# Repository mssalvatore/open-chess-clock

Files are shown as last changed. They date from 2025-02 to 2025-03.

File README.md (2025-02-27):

# Open Chess Clock

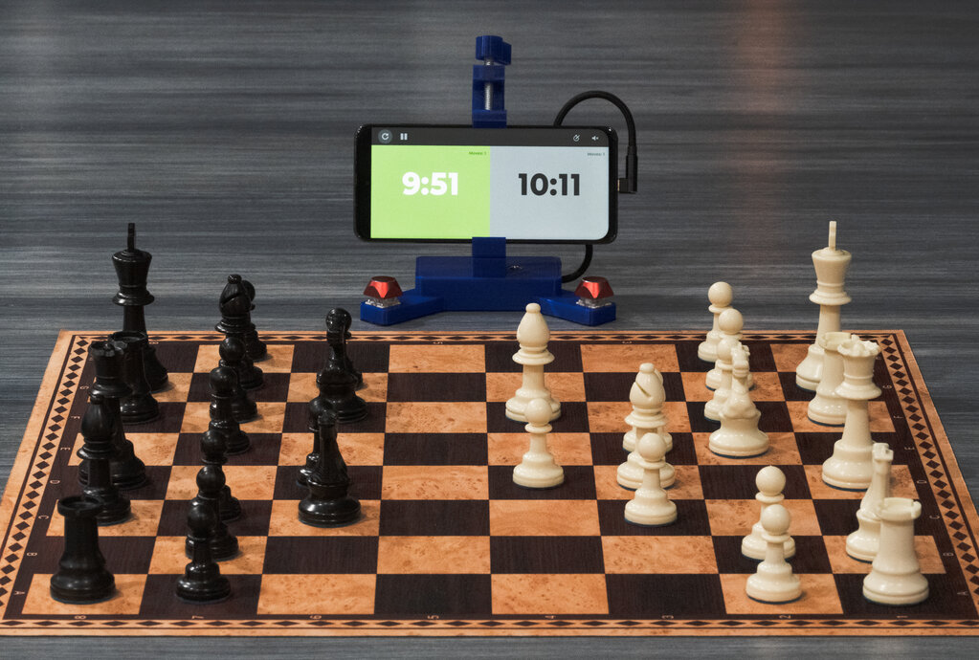
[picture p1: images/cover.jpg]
Open Chess Clock


## Summary
Open Chess Clock is a completely open-source chess/game clock consisting of
both off-the-shelf and 3D-printed parts. The goals of this project are to
create a chess clock that

- is easy and intuitive to set.
- supports multiple time control modes.
- doesn't become a brick if the vendor goes out of business.
- enables the use of clocks with n-player games.
- is inexpensive and accessible.
- is completely customizable.

The first version of this clock is powered by [Chess.com's Android chess clock
app](https://github.com/ChessCom/android-chessclock), which is licensed under
MPL-2.0. This app will likely be replaced in version 2 so that two devices may
be paired in order to play 4-player games and chess variants with time
controls.

## Feature status
| Feature | Status |
| --- | --- |
| Basic time control | ✅ |
| Incremental/Fischer mode | ✅ |
| Bronstein delay | ✅ |
| Simple delay | ✅ |
| 2-player support | ✅ |
| 4-player support | ❌ |
| n-player support | ❌ |
| Android support | ✅ |
| iPhone support | ❌ |

## BOM
### 3D-printed parts
<!-- Add estimated print time -->
| Name | Material | Quantity |
| --- | --- | --- |
| Clock base | PLA | 1 |
| Clock lid | PLA | 1 |
| Phone clamp base | PLA | 1 |
| Phone clamp jaw | PLA | 1 |
| Phone clamp handle | PLA | 1 |
| Phone clamp nut plug (optional) | PLA | 1 |
| Strain relief insert | TPU | 1 |

### Off-the-shelf parts
| Name | Quantity |
| --- | --- |
| 1/4-20 x 2" flat head machine screw | 1 |
| 1/4-20 x 1/2" round/truss head machine screw | 1 |
| 1/4-20 nut | 3 |
| 2.54mm right-angle male header pins | 4 |
| 2.54mm 18-24 AWG female crimp connector | 4 |
| 4-pin DuPont connector housing | 1 |
| 6" USB-C to USB-C cable| 1 |
| #8-32 x 1/2" truss head machine screw | 1 |
| #8-32 nut | 1 |
| 22 AWG stranded wire | 44 cm |
| Adhesive silicone/rubber self-adhesive sheet | 9cm x 16cm |
| Android phone | 1 |
| Arduino Pro Micro-compatible microcontroller (USB-C) | 1 |
| Cherry MX-compatible keycap | 2 |
| Cherry MX-compatible switch | 2 |

## Build instructions

### 1. Print the 3D-printed parts

Print the 3D-printed parts specified in the [BOM](#3d-printed-parts). Slicer
settings for Ultimaker Cura are included in the 3MF files for each part, but
here are some guidelines:

#### Clock base and lid

- Build plate adhesion: Skirt
- Cooling: 0%
- Infill density: 50%
- Layer height: 0.2mm
- Material: PLA
- Supports: Yes
- Support density: 10%

#### Phone clamp

- Build plate adhesion: Brim
- Cooling: 0%
- Infill density: 100%
- Layer height: 0.28mm
- Material: PLA
- Supports: No

#### Strain relief insert

- Build plate adhesion: Skirt
- Cooling: 100%
- Infill density: 25%
- Infill pattern: Gyroid
- Layer height: 0.2mm
- Material: TPU
- Supports: No

### 2. Remove the supports

Remove the supports from the clock base and lid. Pay special attention to the
slot where the microcontroller will be mounted. If the supports are too
difficult to remove, you may need to adjust your slicer settings.

<div align="center">
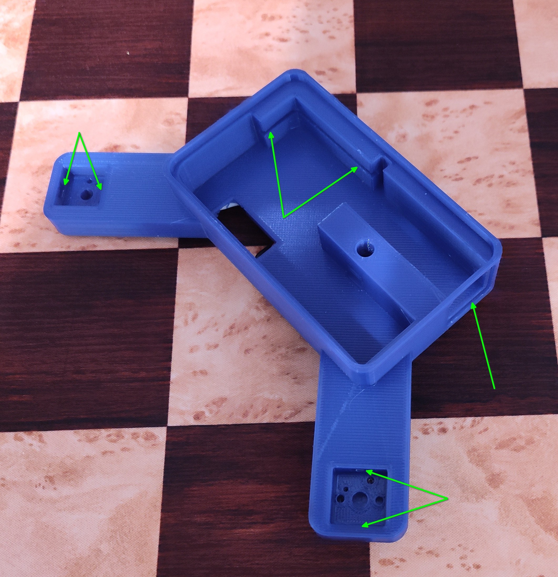
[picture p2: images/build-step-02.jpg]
Build step 2
    
</div>

### 3. Install the wiring

#### 3a. Cut the wires to length

Cut the wires to the following lengths:

- Black (left switch ground): 9cm
- White: 9cm
- Black (right switch ground): 13cm
- Red: 13cm

#### 3b. Install the wires in the wiring channels

Remove the supports in the wiring channels. Line each wire up with its
corresponding slot and note where the switch pins protrude into the wiring
channel. Shave a bit of the insulation from the side of the wire in order to
expose the inner strands so that the switch pins can make good contact.

<div align="center">
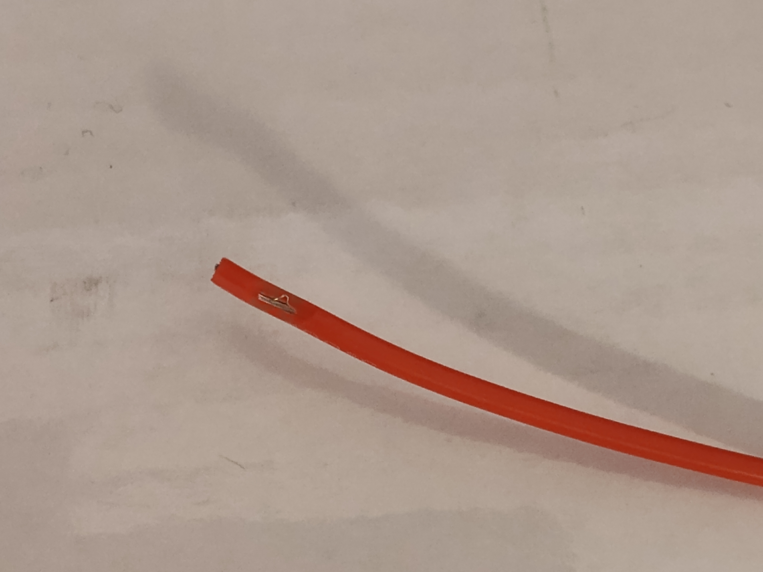
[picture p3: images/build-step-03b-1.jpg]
Build step 3b-1
    
</div>

Press each wire into its corresponding slot, lining up the switch pins with the
exposed wire. Run the wires up into the base through the cutout in the bottom.
<div align="center">
    Build step 3b-2
</div>

#### 3c. Install the DuPont connector

Crimp a 2.54mm 18-24 AWG female crimp connector onto the end of each wire. Plug
the wires into a 4-pin DuPont connector housing. The order of the wires from
left to right is white, red, black, black.

<div align="center">
    Build step 3c
</div>

### 4. Install the switches

Press the switches into the switch sockets on the clock base. Using an
electrical circuit tester, verify that the switches are making good contact
with the wiring by testing for a closed circuit between the data and ground
wires when each switch is pressed.

<div align="center">
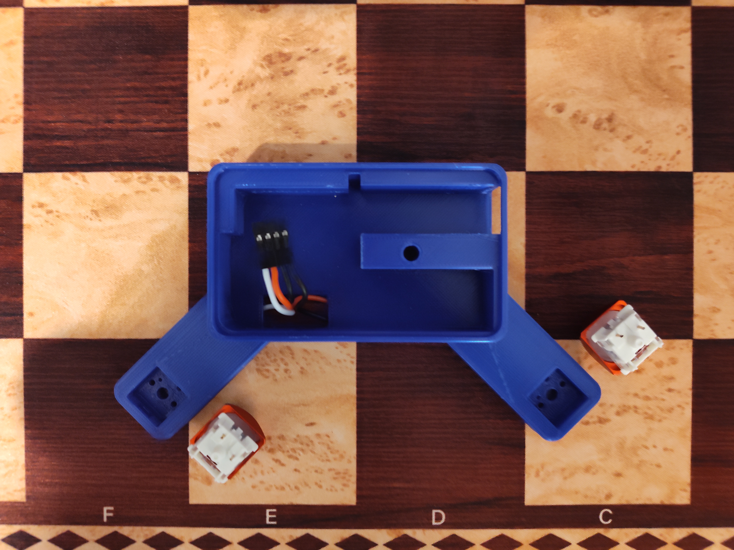
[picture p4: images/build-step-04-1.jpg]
Build step 4-1
    
</div>

<div align="center">
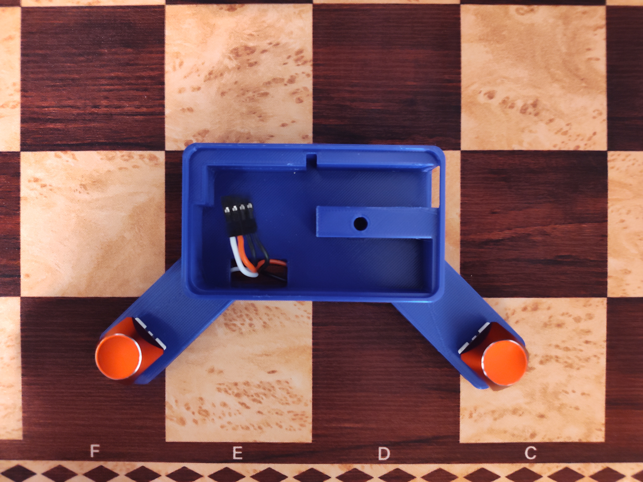
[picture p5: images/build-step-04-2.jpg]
Build step 4-2
    
</div>

### 5. Install the microcontroller

#### 5a. Solder the header pins

Solder the right-angle header pins into the microcontroller's pin holes. Use
the two ground pins, pin 2, and pin 3.

<div align="center">
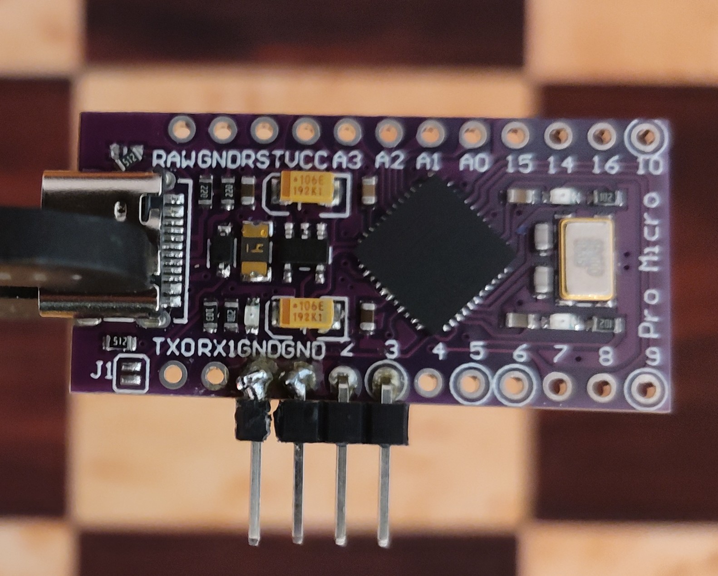
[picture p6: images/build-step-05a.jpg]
Build step 5a
    
</div>

#### 5b. Load the sketch

Using the Arduino IDE, load the [chess-clock.ino](./chess-clock.ino) sketch
onto the microcontroller.

#### 5c. Mount the microcontroller

Slide the microcontroller into the slot in the clock base until it is firmly
seated. The slot should be snug enough to retain the microcontroller, but the
USB cable and strain relief insert will secure it in place.

Attach the DuPont connector to the pins on the microcontroller.

<div align="center">
    Build step 5c
</div>

#### 5d. Install the USB cable

Pass the USB cable and one side of the strain relief insert through the USB
cable channel in the clock base. The hole in the strain relief insert is
slightly off-center (low) in the vertical direction and should align with the USB
port.

<div align="center">
    Build step 5d-1
</div>

Plug the cable into the microcontroller. Press the other side of the strain
relief insert into place. It should fit snugly.

<div align="center">
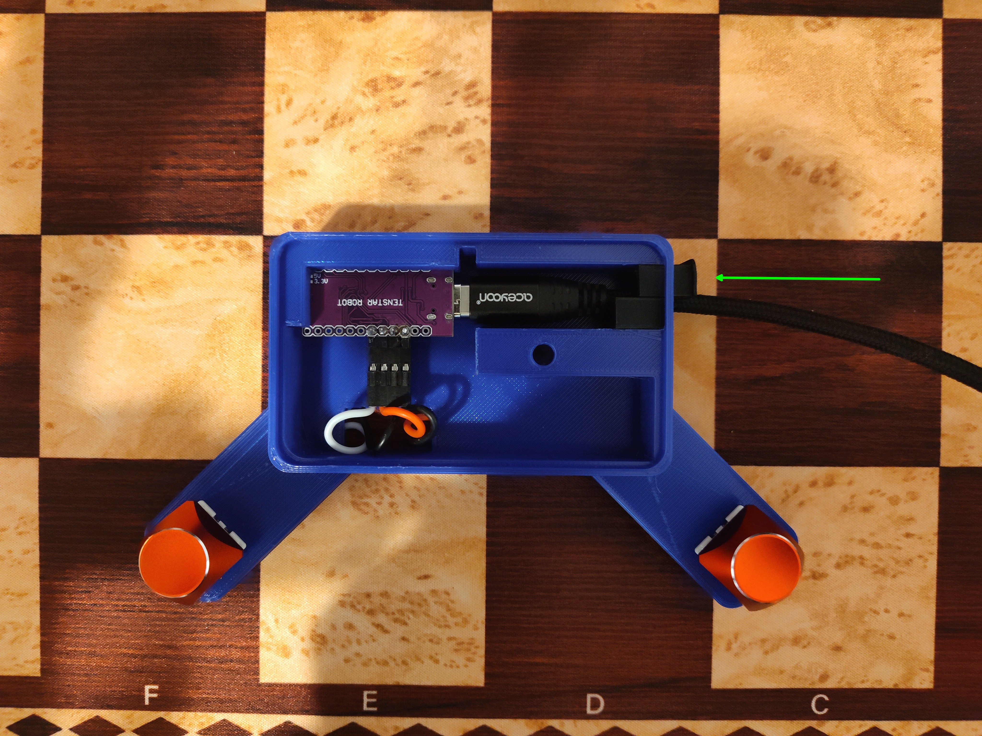
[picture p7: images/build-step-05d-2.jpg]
Build step 5d-2
    
</div>

<div align="center">
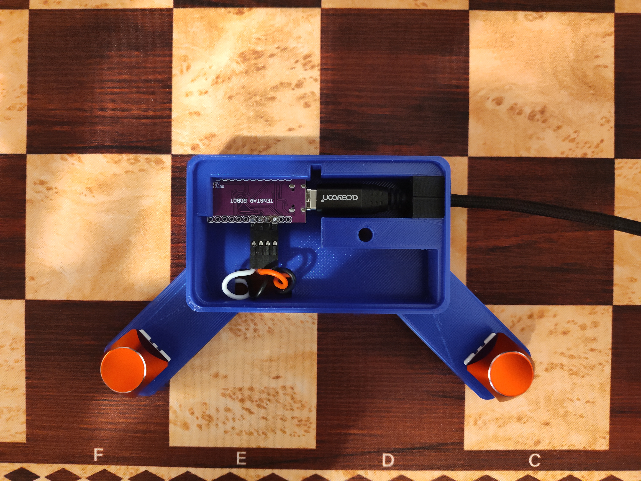
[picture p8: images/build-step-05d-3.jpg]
Build step 5d-3
    
</div>

Now is a good time to test the clock by plugging the USB cable into the Android
device and opening the Chess.com chess clock app. If the buttons do not
properly control the clock, please see the [troubleshooting](#troubleshooting) section.

### 6. Assemble the phone clamp

<div align="center">
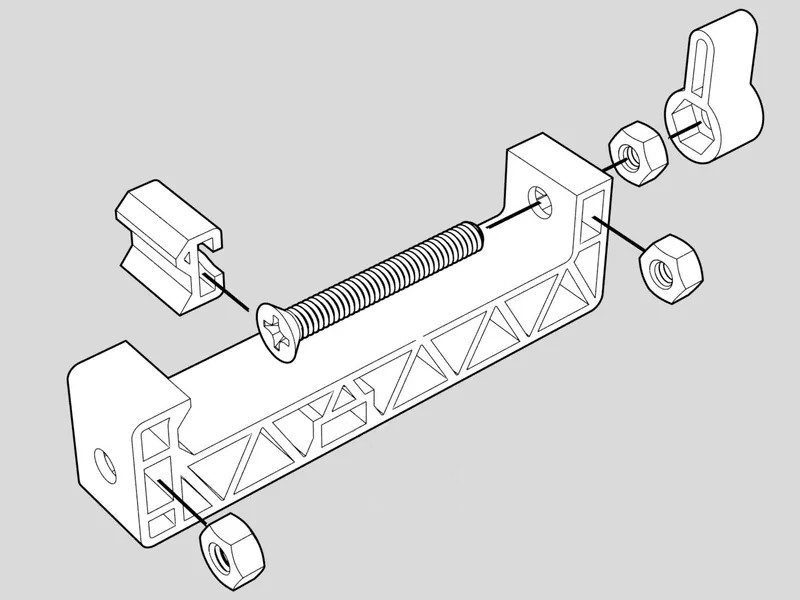
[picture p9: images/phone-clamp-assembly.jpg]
Phone clamp assembly
    
</div>

Slide one nut into the phone clamp base where it will attach to the clock lid.
If the phone clamp nut plug has been printed, press it into the slot following
the nut to secure the nut in place.

Snap the jaw onto the head of the screw. Slide one nut into the top of the
phone clamp base. Push the screw through the top holes of the phone clamp base
and thread it through the nut until it protrudes completely from the top of the phone clamp base.

Thread a third nut onto the screw until 5mm of screw protrudes from the nut.
Using super glue or other appropriate adhesive, glue the nut and screw into the
handle.

### 7. Assemble the clock

#### 7a. Attach the phone clamp to the lid

Using a 1/4-20 x 1/2" round/truss head machine screw, attach the phone clamp to
the clock lid.

<div align="center">
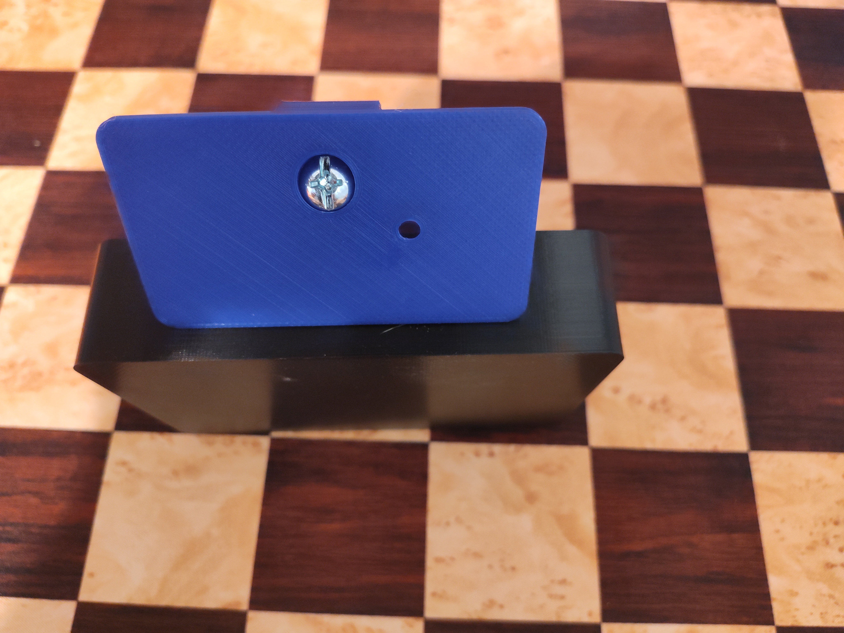
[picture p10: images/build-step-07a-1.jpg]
Build step 7a-1
    
</div>

<div align="center">
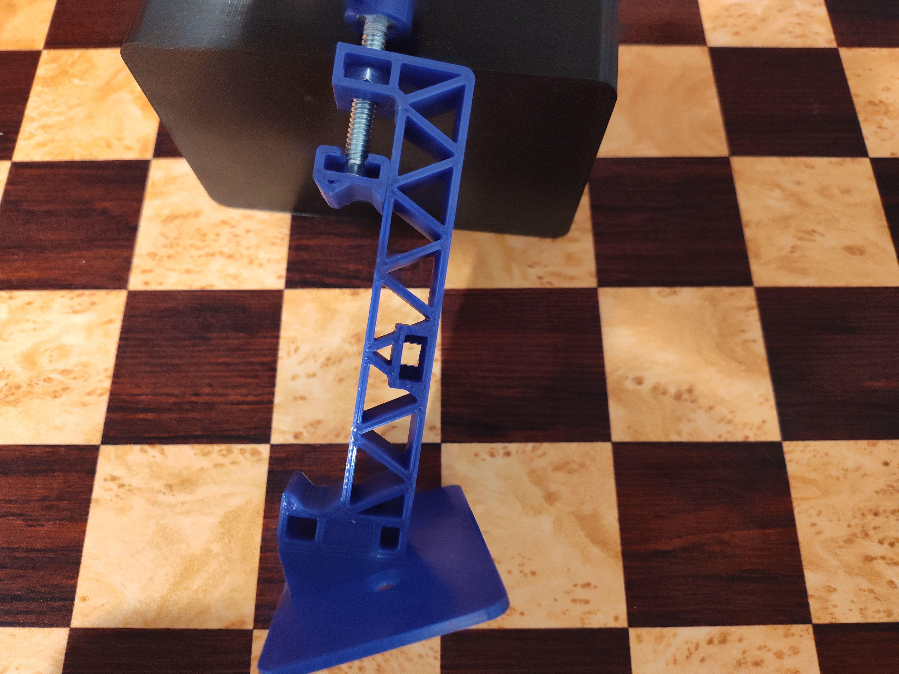
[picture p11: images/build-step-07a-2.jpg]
Build step 7a-2
    
</div>

#### 7b. Attach the lid to the base.

Put the lid onto the base, aligning the screw holes. Place a #8-32 nut into
shaft in the clock base. Thread the #8-32 x 1/2" truss head machine screw
through the hole in the clock lid and into the nut in the clock base.

<div align="center">
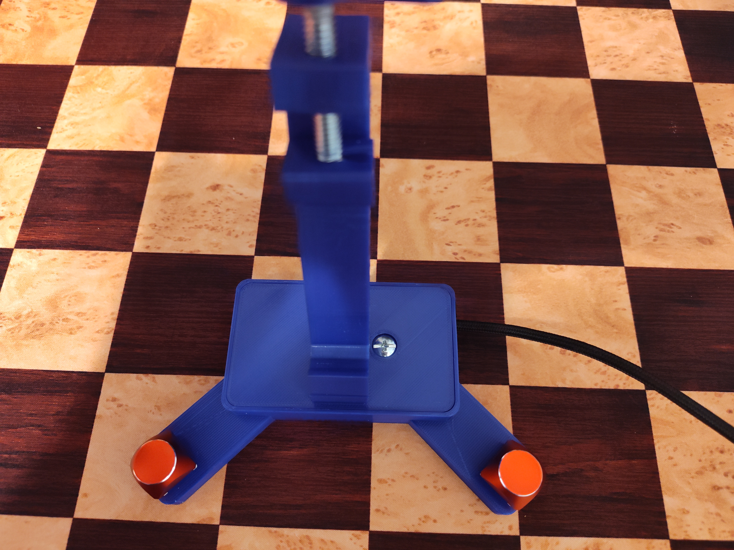
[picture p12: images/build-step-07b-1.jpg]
Build step 7b-1
    
</div>

<div align="center">
    Build step 7b-2
</div>

### 8. Install the phone

#### 8a. Install the Chess.com Chess Clock app

Install the [Chess.com Chess Clock
app](https://play.google.com/store/apps/details?id=com.chess.clock&hl=en_US)
from the Google Play Store.

#### 8b. Clamp the phone in place and test

Place the phone into the phone clamp and tighten gently until the phone is
secure. Plug the USB cable into the phone. Open the Chess Clock app and test.
If the buttons do not control the clock, please see the
[troubleshooting](#Troubleshooting) section.

<div align="center">
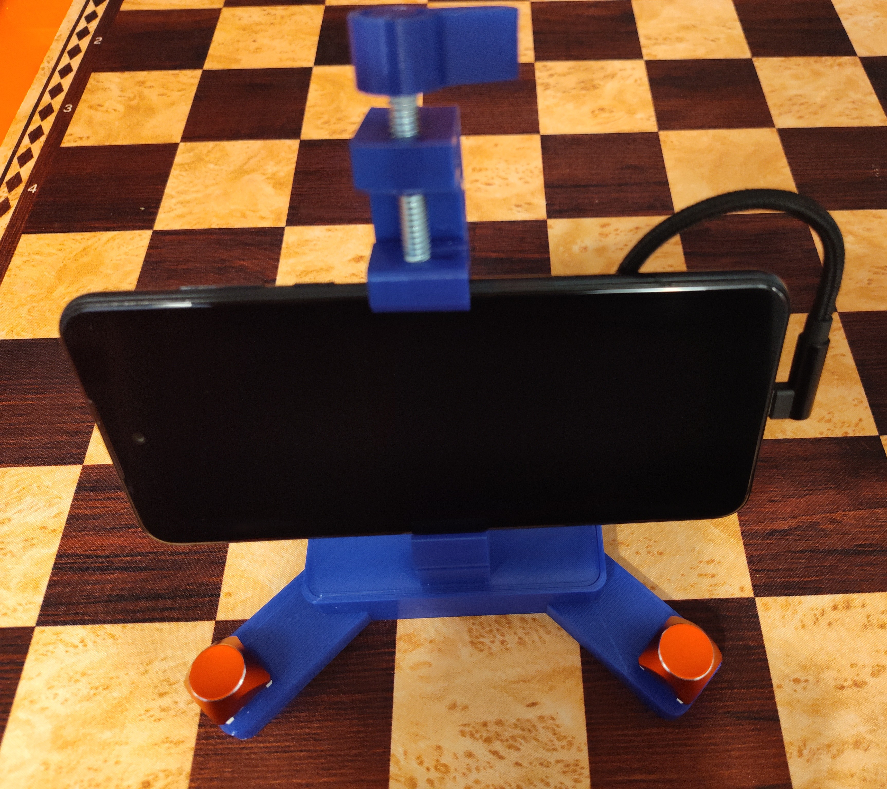
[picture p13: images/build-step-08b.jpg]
Build step 8b
    
</div>

### 9. Install anti-slip material

Using a self-adhesive, anti-slip sheet of rubber, silicone, or similar
material, stick the bottom of the clock base to the material. Using a sharp
utility knife, carefully trim the excess material from the edges of the base.

NOTE: Do not do this step until you are sure that the wiring is properly
installed and the clock works as intended.

## Troubleshooting

### The microcontroller does not power on when plugged into the phone

When the microcontroller is plugged into the phone, LEDs on the microcontroller
should light up. If the microcontroller is already installed into the clock
base, you'll see these lights reflecting off of the bottom of the base.

On some Android devices, the mirocontroller will only be recognized if the
USB-C cable is oriented in a specific way. This can vary depending on the specific
Android device, microcontroller, and USB cable that are used. Try rotating the
USB-C cable 180 degrees in the microcontroller's port and/or the Android
device's port.

### The microcontroller powers on but does not control the clock

#### Check the wiring

Using an electrical circuit tester, verify that the switches are making good
contact with the wiring by testing for a closed circuit between the data and
ground wires when each switch is pressed. Perform the same test on the pins of
the microcontroller to check that the solder joints are making good contact.
When the left switch is pressed, the tester should indicate a closed circuit
between pin 3 and both ground pins. When the right switch is pressed, the
tester should indicate a closed circuit between pin 2 and both ground pins.

#### Test the keyboard functionality

Modify the [chess-clock.ion](./chess-clock.ino) sketch to press ASCII keys
instead of the clock control keystrokes. Plug the microcontroller into the
phone. Select any app/field that expects text as input. Press the left switch
and verify that the letter 'a' is typed. Press the right switch and verify that
the letter 'b' is typed. If neither letter is typed, connect the
microcontroller to a computer and try the same test.

```diff
diff --git a/chess-clock.ino b/chess-clock.ino
index 807be7b..8403ec3 100644
--- a/chess-clock.ino
+++ b/chess-clock.ino
@@ -13,9 +13,9 @@ const int RIGHT_DOWN = 5;

 int current_state = IDLE;

-const int LEFT_KEY_SEQUENCE[] = {KEY_DOWN_ARROW, KEY_DOWN_ARROW, KEY_LEFT_ARROW, KEY_RETURN};
+const int LEFT_KEY_SEQUENCE[] = {'a'};
 const int LEFT_KEY_SEQUENCE_SIZE = sizeof(LEFT_KEY_SEQUENCE) / sizeof(LEFT_KEY_SEQUENCE[0]);
-const int RIGHT_KEY_SEQUENCE[] = {KEY_DOWN_ARROW, KEY_DOWN_ARROW, KEY_RIGHT_ARROW, KEY_RETURN};
+const int RIGHT_KEY_SEQUENCE[] = {'b'};
 const int RIGHT_KEY_SEQUENCE_SIZE = sizeof(RIGHT_KEY_SEQUENCE) / sizeof(RIGHT_KEY_SEQUENCE[0]);

 void setup() {
```

## Acknowledgements

Thanks to [pixel2](https://www.printables.com/@pixel2_237985) for the
[3D-printed phone
clamp](https://www.printables.com/model/233032-phone-clamp-for-tripod/files).

Thanks to [Chess.com](https://chess.com) for the [Android chess clock
app](https://play.google.com/store/apps/details?id=com.chess.clock&hl=en_US).

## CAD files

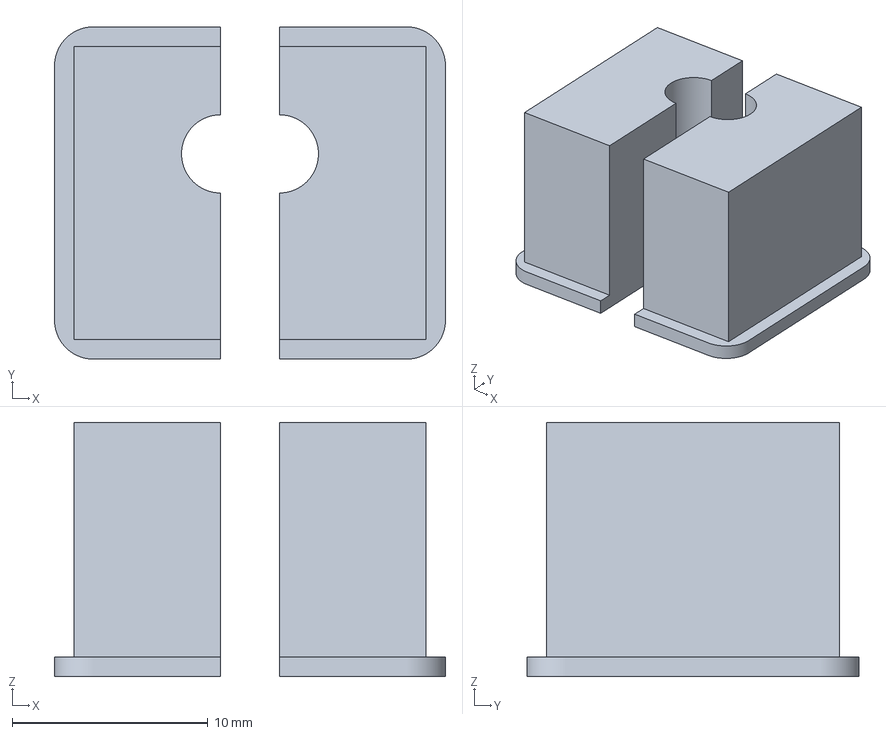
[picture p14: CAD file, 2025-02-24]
model/cura/strain-relief.3mf
20.0 x 17.0 x 13.0 mm

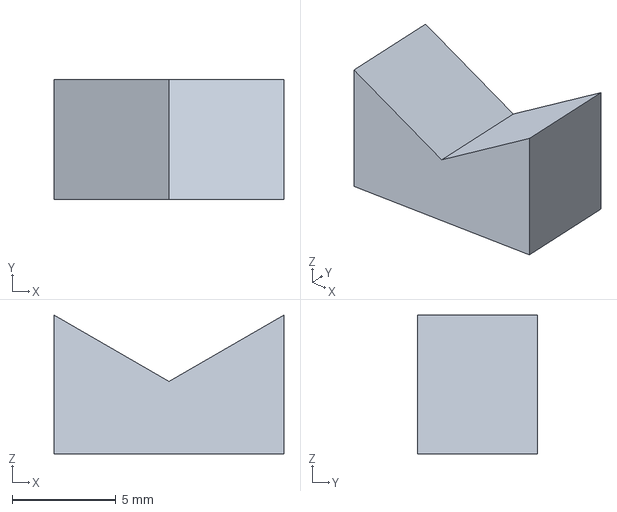
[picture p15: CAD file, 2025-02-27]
model/cura/phone-clamp-nut-plug.3mf
11.1 x 5.80 x 6.70 mm

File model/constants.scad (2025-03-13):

include <hotswap_pcb_generator/scad/parameters.scad>

fillet = 5;

body_wall_thickness = 2.5;

socket_dimension = socket_size + (h_border_width * 2);
switch_platform_z = 9;
switch_border = 3;
switch_platform_x = socket_dimension + 2 * switch_border;
switch_platform_y = socket_dimension + switch_border + 40;
switch_z_offset = pcb_thickness / 2;

controller_x = 18;
controller_y = 36.2;
controller_z = 2;
controller_wall_thickness = 1.75;
controller_insert_depth = 2.6;

controller_top_clearance = 5;
controller_bottom_clearance = 7.5;

controller_mount_long_side_x = controller_y;
controller_mount_long_side_y = controller_wall_thickness + controller_insert_depth;
controller_mount_long_side_z = controller_bottom_clearance + controller_z + controller_top_clearance;

controller_mount_short_side_x = controller_mount_long_side_y;
controller_mount_short_side_y = controller_x;
controller_mount_short_side_z = controller_mount_long_side_z;


cavity_x = controller_mount_long_side_x + controller_mount_short_side_x - controller_insert_depth + 5;
cavity_y = 48;
cavity_z = controller_mount_long_side_z;

cable_channel_dimension = cavity_z;

cable_channel_xpos = cavity_x / 2 - .001;
cable_channel_ypos = -(controller_mount_long_side_y - controller_insert_depth + (controller_x / 2) - cable_channel_dimension / 2);

wire_slot_x = cavity_x / 2;
wire_slot_y = wire_slot_x / 2;

usb_cable_connector_length = 40;

strain_relief_x = cavity_z + .5;
strain_relief_y = cavity_z + .5;
strain_relief_z = 12;


strain_relief_lip = 2;
strain_relief_lip_z = 1;
strain_relief_fillet = 2;

cavity_border = 3;
lid_z = 2.65;
floor_thickness = 3;
platform_x = cavity_x + usb_cable_connector_length + 7;
platform_y = cavity_y + 2 * cavity_border; // TODO: Fix magic number
platform_z = cavity_z + floor_thickness + lid_z; // TODO: Fix magic number

// TODO: Fix magic number
cable_channel_length = platform_x - cavity_x - 2 * cavity_border + body_wall_thickness + .502;

phone_theta = 22.5;

phone_clamp_width = 31;
phone_clamp_depth = 20.95;
phone_clamp_screw_shaft_diameter = 7;
phone_clamp_screw_head_diameter = 12;
phone_clamp_screw_head_height =  5;
phone_clamp_screw_hole_ypos = -cos(phone_theta) * lid_z;
phone_clamp_screw_gap = 4.35;

lid_screw_shaft_diameter = 5;
lid_screw_head_diameter = 10;
lid_screw_head_height = 1.6;
lid_nut_diameter = 10.4;
lid_screw_xpos = phone_clamp_depth / 2 + lid_screw_head_diameter / 2 + 1;

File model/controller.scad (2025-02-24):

include <BOSL/constants.scad>
use <BOSL/shapes.scad>
use <BOSL/transforms.scad>

include <constants.scad>

slot_zpos = controller_bottom_clearance - (controller_z / 2);

module controller_mount() {
    controller_total_x = controller_mount_short_side_x + controller_mount_long_side_x;
    xpos = (controller_mount_short_side_x - controller_insert_depth) / 2 - (cavity_x - controller_total_x) / 2;
    ypos = -controller_mount_long_side_y + cavity_y / 2;

    move([xpos, ypos, 0]){
        difference() {
            union() {
                controller_mount_long_side();
                controller_mount_short_side();
            }
        }
    }
}

module controller_mount_long_side() {
    alignment=V_TOP + V_BACK;

    slot_xpos = -(controller_mount_long_side_x - controller_y) / 2 + .001;
    slop_ypos = -.001;

    difference() {
        cuboid(
            [
                controller_mount_long_side_x,
                controller_mount_long_side_y,
                controller_mount_long_side_z
            ],
            align=alignment
        );
        move([slot_xpos, -.001, slot_zpos]) {
            cuboid([controller_y + 1, controller_insert_depth, controller_z], align=alignment);
        }
    }
}

module controller_mount_short_side() {
    alignment = V_TOP + V_FRONT + V_LEFT;

    slot_xpos = .001;
    slot_ypos = -.001;

    xpos = -(controller_mount_long_side_x / 2 - controller_insert_depth / 2 - .001);
    ypos = controller_mount_long_side_y;

    move([xpos, ypos, 0]) {
        difference() {
            cuboid(
                [
                    controller_mount_short_side_x,
                    controller_mount_short_side_y,
                    controller_mount_short_side_z
                ],
                align=alignment
            );
            move([slot_xpos, slot_ypos, slot_zpos]) {
                cuboid([controller_insert_depth, controller_x, controller_z], align=alignment);
            }
        }
    }
}

module controller_cavity() {
    ymove(cavity_y / 2) {
        cuboid([cavity_x, cavity_y, cavity_z], fillet=fillet, edges=EDGES_Z_LF, align=V_TOP + V_FRONT);
        move([cable_channel_xpos, cable_channel_ypos, 0]) {
            cuboid(
                [cable_channel_length, cable_channel_dimension, cable_channel_dimension],
                align=V_TOP + V_FRONT + V_RIGHT
            );
        }
        move([0, -cavity_y, 0.001]) {
            cuboid([wire_slot_x, wire_slot_y, 5], align=V_BOTTOM + V_BACK);
        }
        strain_relief_recess();
    }
}

module strain_relief_recess() {
    tolerance = 0.35;
    cutout_x = strain_relief_lip_z + tolerance;
    cutout_y = cavity_z + strain_relief_lip + 2 * tolerance;
    cutout_z = cavity_z + strain_relief_lip + 2 * tolerance;

    xpos = cavity_x / 2  + cable_channel_length - cutout_x + .001;
    ypos = cable_channel_ypos + (strain_relief_lip / 2 + tolerance);
    zpos = -(strain_relief_lip / 2 + tolerance);

    move([xpos, ypos, zpos]) {
        cuboid(
            [
                cutout_x,
                cutout_y,
                cutout_z
            ],
            fillet = strain_relief_fillet + tolerance,
            edges=EDGES_X_ALL,
            align=V_TOP + V_FRONT + V_RIGHT
        );
    }
}

*intersection() {
    controller_mount();
    #cuboid([controller_mount_long_side_x, controller_mount_short_side_y + 10, 20], align=V_BACK + V_TOP + V_LEFT);
}
controller_mount();

*controller_cavity();

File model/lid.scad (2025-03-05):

include <BOSL/constants.scad>
use <BOSL/shapes.scad>
use <BOSL/transforms.scad>

include <constants.scad>

lid_lip = 1;
lid_x = platform_x - body_wall_thickness - lid_lip;
lid_y = platform_y- body_wall_thickness - lid_lip;
lid_tolerance = 0.2;



wedge_y = cos(phone_theta) * phone_clamp_width;
wedge_ypos = -((lid_y - wedge_y) / 2 - body_wall_thickness);

wedge_z = sin(phone_theta) * phone_clamp_width;
wedge_wall_thickness = 3;
wedge_wall_height = 3;

module lid_cutout() {
    zpos = platform_z - lid_z - .003;

    zmove(zpos) {
        cuboid(
            [lid_x + lid_tolerance, lid_y + lid_tolerance, lid_z + .004],
            fillet=fillet,
            edges=EDGES_Z_ALL, align=V_TOP
        );
    }
}

module lid() {
    difference() {
        union() {
            cuboid([lid_x, lid_y, lid_z], fillet=fillet, edges=EDGES_Z_ALL, align=V_TOP);
            wedge();
        }
        ymove(wedge_ypos) {
            phone_clamp_screw_channel();
        }
        lid_screw();
    }
}

module wedge() {
    move([0, wedge_ypos, lid_z - .001]) {
        zrot(90) {
            right_triangle([wedge_y, phone_clamp_depth, wedge_z], align=V_TOP + V_CENTER);
            zmove(wedge_wall_height) {
                wedge_walls();
            }
        }
    }
}

module wedge_walls() {
    yspread(phone_clamp_depth + wedge_wall_thickness - .002, n=2) {
        zmove(-.001) {
            right_triangle([wedge_y,  wedge_wall_thickness, wedge_z], align=V_TOP + V_CENTER);
        }
        cuboid( [wedge_y, wedge_wall_thickness, wedge_wall_height], align=V_BOTTOM + V_CENTER);
    }
}

module phone_clamp_screw_channel() {
    channel_y = 50;

    ypos = phone_clamp_screw_hole_ypos + phone_clamp_screw_shaft_diameter / 2;
    zpos = lid_z + tan(phone_theta) * ((wedge_y / 2) - ypos) ;

    screw_head_y_offset = (phone_clamp_screw_head_diameter - phone_clamp_screw_shaft_diameter) / 2;

    move([0, ypos, zpos]) {
        xrot(-phone_theta) {
            zmove(-phone_clamp_screw_gap) {
                cuboid(
                    [phone_clamp_screw_shaft_diameter, channel_y, phone_clamp_screw_gap],
                    align=V_TOP + V_FRONT
                );
                cyl(d=phone_clamp_screw_shaft_diameter, h=phone_clamp_screw_gap, align=V_TOP);
                move([0, screw_head_y_offset, .001]) {
                    cuboid(
                        [
                            phone_clamp_screw_head_diameter,
                            channel_y,
                            phone_clamp_screw_head_height + 1
                        ],
                        align=V_BOTTOM + V_FRONT
                    );
                cyl(
                    d=phone_clamp_screw_head_diameter,
                    h=phone_clamp_screw_head_height + 1,
                    align=V_BOTTOM
                );
                }
            }
        }
    }

}

module lid_screw() {
    screw_head_height_adjustment = 30;

    move([lid_screw_xpos, 0, lid_z +.001]) {
        zmove(screw_head_height_adjustment) {
            cyl(
                d=lid_screw_head_diameter,
                h=lid_screw_head_height + screw_head_height_adjustment,
                align=V_BOTTOM
            );
        }
        zmove(-.001) {
            cyl(d=lid_screw_shaft_diameter, h=platform_z, align=V_BOTTOM);
        }

    }
}

lid();

*intersection() {
    lid();
    ymove(8)
    zmove(-.001)
    cuboid([28, 50, 20], align=V_TOP + V_FRONT);
}

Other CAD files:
model/renders/strain-relief.stl
model/renders/phone-clamp-nut-plug.stl
model/phone-clamp-nut-plug.scad
model/platform.scad
model/strain-relief.scad
model/switches.scad

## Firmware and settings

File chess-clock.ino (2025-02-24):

#include <Keyboard.h>
const int debounce = 5;

const int LEFT_SWITCH = 3;
const int RIGHT_SWITCH = 2;

const int IDLE=0;
const int PAUSE = 1;
const int PAUSE_LEFT = 2;
const int PAUSE_RIGHT = 3;
const int LEFT_DOWN = 4;
const int RIGHT_DOWN = 5;

int current_state = IDLE;

const int LEFT_KEY_SEQUENCE[] = {KEY_DOWN_ARROW, KEY_DOWN_ARROW, KEY_LEFT_ARROW, KEY_RETURN};
const int LEFT_KEY_SEQUENCE_SIZE = sizeof(LEFT_KEY_SEQUENCE) / sizeof(LEFT_KEY_SEQUENCE[0]);
const int RIGHT_KEY_SEQUENCE[] = {KEY_DOWN_ARROW, KEY_DOWN_ARROW, KEY_RIGHT_ARROW, KEY_RETURN};
const int RIGHT_KEY_SEQUENCE_SIZE = sizeof(RIGHT_KEY_SEQUENCE) / sizeof(RIGHT_KEY_SEQUENCE[0]);

void setup() {
  pinMode(LEFT_SWITCH, INPUT_PULLUP);
  pinMode(RIGHT_SWITCH, INPUT_PULLUP);

  Keyboard.begin();

}

int debounce_read(int pin) {
  if (digitalRead(pin) == LOW) {
    delay(debounce);
    return digitalRead(pin);
  }

  return HIGH;
}

void press_keys(int keys[], int num_keys) {
    for (int i = 0; i < num_keys; i++) {
        Keyboard.write(keys[i]);
        delay(10);
    }
}

void press_left() {
    press_keys(LEFT_KEY_SEQUENCE, LEFT_KEY_SEQUENCE_SIZE);
}

void press_right() {
    press_keys(RIGHT_KEY_SEQUENCE, RIGHT_KEY_SEQUENCE_SIZE);
}

void pause() {
    // NOP
}


void loop() {
    if (debounce_read(LEFT_SWITCH) == LOW) {
        if (current_state == IDLE) {
            press_left();
            current_state = LEFT_DOWN;
        }
        else if (current_state == RIGHT_DOWN) {
            pause();
            current_state = PAUSE;
        }
        else if (current_state == PAUSE_RIGHT) {
            current_state = PAUSE;
        }
    }
    else {
        if (current_state == LEFT_DOWN || current_state == PAUSE_LEFT) {
            current_state = IDLE;
        }
        else if (current_state == PAUSE) {
            current_state = PAUSE_RIGHT;
        }
    }

    if (debounce_read(RIGHT_SWITCH) == LOW) {
        if (current_state == IDLE) {
            press_right();
            current_state = RIGHT_DOWN;
        }
        else if (current_state == LEFT_DOWN) {
            pause();
            current_state = PAUSE;
        }
        else if (current_state == PAUSE_LEFT) {
            current_state = PAUSE;
        }
    }
    else {
        if (current_state == RIGHT_DOWN || current_state == PAUSE_RIGHT) {
            current_state = IDLE;
        }
        else if (current_state == PAUSE) {
            current_state = PAUSE_LEFT;
        }
    }

    delay(5);
}

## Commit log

2025-02-08 Add model body and lid
    [body.scad, constants.scad]
2025-02-09 Adjust lid z height to properly recess switches
    [constants.scad]
2025-02-09 Remove excess space around switch socket
    [body.scad, constants.scad]
2025-02-09 Fix slanted body hollow
    [body.scad, constants.scad]
2025-02-09 Add PCB mount
    [body.scad, constants.scad]
2025-02-09 Fix incorrect body_hollow_y_top calculation
    [constants.scad]
2025-02-09 Cutout phone socket
    [body.scad, constants.scad]
2025-02-09 Adjust frame for equal border
    [constants.scad]
2025-02-09 Fix pcb_thickness name collision
    This is already defined in hotswap_pcb_generator
    [body.scad, constants.scad]
2025-02-09 Remove extraneous cuboid from phone_socket_cutout()
    [body.scad]
2025-02-09 Add top backplate to phone socket
    [body.scad, constants.scad]
2025-02-09 Add bottom backplate
    [body.scad]
2025-02-09 Add vertical backplates
    [body.scad, constants.scad]
2025-02-09 Adjust phone_x to fit within the printer bed
    [constants.scad]
2025-02-09 Cutout relief for usb cable
    [body.scad, constants.scad]
2025-02-09 Define body_z in terms of phone_y
    [body.scad, constants.scad]
2025-02-10 Redesign PCB mount
    [body.scad, constants.scad]
2025-02-10 Fix trigonometry
    [body.scad, constants.scad]
2025-02-11 Fix more trigonometry
    [body.scad, constants.scad]
2025-02-11 Fix backplate z center
    [body.scad]
2025-02-11 Reduce body_y
    [constants.scad]
2025-02-11 Fix placement of pcb_mount
    [body.scad]
2025-02-11 Reduce body_theta
    [constants.scad]
2025-02-11 Add tension bar cutout
    [body.scad, constants.scad]
2025-02-11 Rename body_theta -> theta
    [body.scad, constants.scad]
2025-02-12 Add wiring channels to lid
    [body.scad, constants.scad]
2025-02-12 Thin the side walls
    [body.scad, constants.scad]
2025-02-12 Adjust wire channel placement
    Since I'm not using the diode, I need the wiring channel in a different
    spot.
    [body.scad]
2025-02-12 Add tension bar cutout spring holes
    [body.scad, constants.scad]
2025-02-12 Adjust wire diameter
2025-02-12 Adjust wire channel placement
    [body.scad]
2025-02-12 Improve switch socket
    - Tighter fit for the switch
    - Add latches
    [body.scad, constants.scad]
2025-02-12 Disable column wire in switch socket
2025-02-12 Disable unnecessary channels in switch socket
2025-02-12 Adjust PCB mount
    - Angles the PCB mount towards the phone
    - Improves tolerances
    [body.scad, constants.scad]
2025-02-13 Add cable channel
    [body.scad, constants.scad]
2025-02-13 Adjust cable dimensions
    [constants.scad]
2025-02-14 Remove lid tolerance
    Strangely, this isn't needed to get the lid to fit. There must be some
    shrinkage that occurs when the lid cools.
    [body.scad, constants.scad]
2025-02-14 Reduce central switch pin radius for a tighter fit
2025-02-14 Rename pcb -> controller
    [body.scad, constants.scad]
2025-02-14 Extract controller_mount() into controller.scad
    [body.scad, constants.scad, controller.scad]
2025-02-15 Redesign controller mount with cable strain relief
    [body.scad, constants.scad, controller.scad]
2025-02-16 Add button relief
    [body.scad]
2025-02-16 Simplify/Redesign the tension bar
    There are a number of design issues with the spring-loaded tension bar.
    This redesign simplifies things in order to get v1 out.
    [body.scad, constants.scad, tension-bar.scad]
2025-02-16 Add tension bar insert gcode and renders
    [tension-bar-inserts.stl]
2025-02-16 Fix tension-bar.scad formatting
    [tension-bar-inserts.stl, tension-bar.scad]
2025-02-16 Extract lid into lid.scad
    [body.scad, lid.scad]
2025-02-16 Set switch socket $fn=256
2025-02-16 Relocate the tension bar cutout
    [body.scad, constants.scad, tension-bar.scad]
2025-02-17 Reduce size
    [body.scad, constants.scad, controller.scad]
2025-02-17 Add switch platform
    [constants.scad, switches.scad]
2025-02-17 Cut wire channels in switch platform
    [switches.scad]
2025-02-17 Redesign controller mount/cavity
    [controller.scad]
2025-02-20 Build the new platform/body
    [constants.scad, controller.scad, platform.scad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]
2025-02-20 Improve the new design
    [platform.scad]
2025-02-20 Make more design improvements
    [constants.scad, platform.scad, switches.scad]
2025-02-20 Adjust lid fit
    [platform.scad]
2025-02-20 Adjust cavity for better controller fit
    [constants.scad, controller.scad, platform.scad]
2025-02-20 Adjust switch fit
    [switches.scad]
2025-02-20 Add phone-clamp nut plug
    [phone-clamp-nut-plug.scad, phone-clamp-nut-plug.stl]
2025-02-20 Extend switches
    [constants.scad]
2025-02-20 Improve phone clamp nut plug
    [phone-clamp-nut-plug.scad]
2025-02-20 Improve lid fit
    [platform.scad]
2025-02-20 Increase wall thickness
    [platform.scad]
2025-02-20 Fix floor/lid thickness
    [platform.scad]
2025-02-21 Widen the base to make room for the USB cable/strain relief
    [constants.scad, platform.scad]
2025-02-21 Improve controller mount
    [controller.scad]
2025-02-21 Fix body cavity
    [platform.scad]
2025-02-21 Reduce slicing artifacts
    [controller.scad, platform.scad]
2025-02-21 Add strain relief
    [strain-relief.3mf, strain-relief.scad, strain-relief.stl]
2025-02-22 Add arduino microcontroller code
2025-02-23 Remove stale artifacts from the first design
    [body.scad, constants.scad, lid.scad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]
2025-02-23 Adjust wire fit
    [switches.scad]
2025-02-24 Add a recess for the strain relief pieces
    [constants.scad, controller.scad, platform.scad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]
2025-02-27 Rerender the phone clamp nut plug
    [phone-clamp-nut-plug.3mf, phone-clamp-nut-plug.stl]
2025-03-05 Add phone clamp screw channel for easy disassembly
    [platform.scad]
2025-03-05 Extract lid components into lid.scad
    [constants.scad, lid.scad, platform.scad]
2025-03-05 Refactor lid.scad
    [lid.scad]
2025-03-13 Adjust phone clamp dimensions
    [constants.scad]
